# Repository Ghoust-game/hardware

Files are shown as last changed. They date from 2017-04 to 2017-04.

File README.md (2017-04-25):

# GHOUST HARDWARE

This repository is all about the **HARDWARE** used in the **GHOUST** game

You find eagle (v6) files in here
- .sch Schematics
- .brd Board layout files
- .pdf files of the Schematics 
- Bill of Materials
- Links to all Parts

Also GERBER files are provided if you want to make your own Boards

If you expect / need something that is not here, please let us know via email: team@ghou.st

Information on sourcing the parts is available on the [wiki](https://github.com/Ghoust-game/hardware/wiki).

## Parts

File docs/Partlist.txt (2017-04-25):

Part     Value            Package                     Link    

C1       0.1uF            0805                        http://mouser.com    
C2                        CPOL-RADIAL-100UF-25V       http://mouser.com   
C3       0.1uF            0805                        http://mouser.com   

D2                        SOD-123FL                   http://mouser.com   

Q2       MMBT5088         SOT23-3                     http://mouser.com   

R1       10K              R0805                       http://mouser.com    
R2       10K              R0805                       http://mouser.com   
R3       1K               R0805                       http://mouser.com   
R4       1K               R0805                       http://mouser.com   
R5       1K               R0805                       http://mouser.com   
R6       1K               R0805                       http://mouser.com   
R7       100ohm 	  R0805                       http://mouser.com   
R8       56K pullup       R0805                       http://mouser.com   

IC1      AMS1117          SOT223                      http://www.electrodragon.com/product/10pcs-ams1117-lm1117-1117-3-3v-1a-voltage-regulator/

U$1      MMA845X_BREAKOUT MMA845XBOB                  http://www.electrodragon.com/product/triple-axis-accelerometer-breakout/    
U$2      B3F-10XX_DEV     B3F-10XX                    http://www.electrodragon.com/product/mini-push-button-switch/
U$8      TRANSDUCER       BMT1205XH7.5                https://www.reichelt.at/Alarmmelder/SUMMER-EPM-121/3/index.html?ACTION=3&GROUPID=3484&ARTICLE=35927      
U$11     MICROSWITCH       			      https://www.aliexpress.com/item/6-7-2-7-1-5-3pin-slide-switch-New-products-and-ROHS/455478700.html
U$12     VIBROMOTOR       VIBRO                       https://de.aliexpress.com/item/3-Pcs-1400RPM-Speed-3V-Mobile-Phone-Micro-DC-Coin-Vibration-Motor/32695914166.html    
U$13     LIPO             LIPOCON                     https://www.aliexpress.com/item/100pcs-XH-2-5-2-54mm-2P-3P-4P-5P-6P-Female-Right-Angle-Connector-Pitch/32755811521.html
X2                        ESP-12                      http://www.electrodragon.com/product/esp-12s-wifi-module-esp8266/

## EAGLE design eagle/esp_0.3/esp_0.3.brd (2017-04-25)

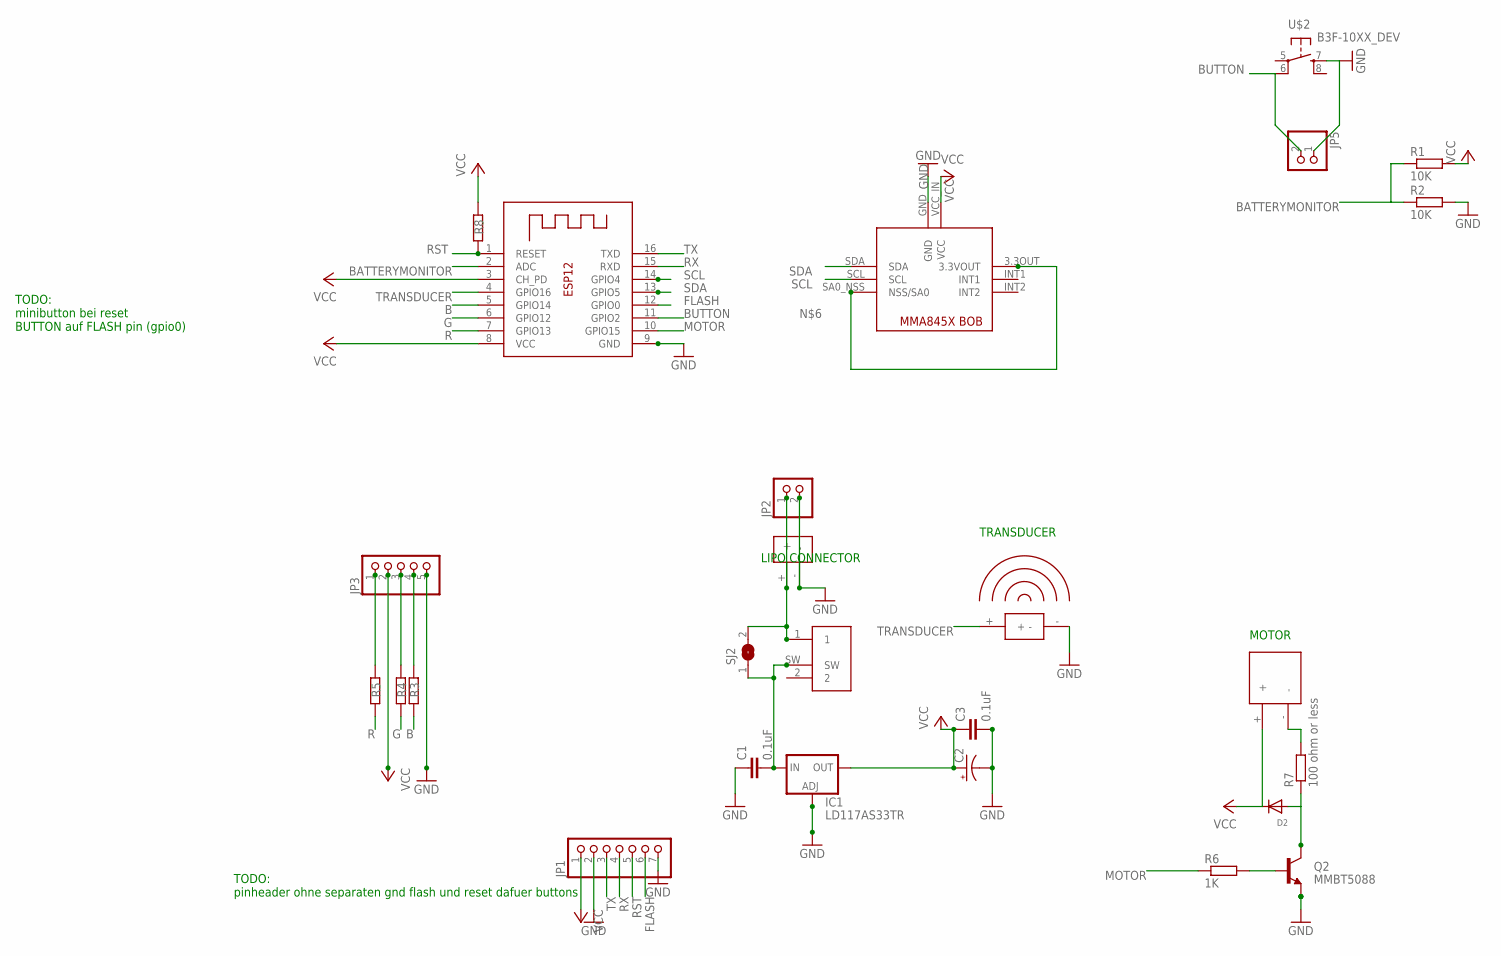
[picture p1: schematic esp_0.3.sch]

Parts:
C1, C3: 0.1uF; 0805
C2: 100UF-25V-20%(PTH); CPOL-RADIAL-100UF-25V
D2: DIODE_SOD-123FL; SOD-123FL
IC1: LD117AS33TR; SOT223
JP1: PINHD-1X7; 1X07
JP2: PINHD-1X2; 1X02
JP3: PINHD-1X5; 1X05
JP5: PINHD-1X2/90; 1X02/90
Q2: MMBT5088; SOT23-3
R1, R2: 10K; R0805
R3, R4, R5, R6: 1K; R0805
R7: 100 ohm or less; R0805
R8: 56K pullup; R0805
SJ2: SJ
U$1: MMA845X_BREAKOUT; MMA845XBOB
U$2: B3F-10XX_DEV; B3F-10XX
U$8: TRANSDUCER; BMT1205XH7.5
U$11: MICROSWITCH; MICR_SCHIEBESCHALTER_CHINA_PAC
U$12: VIBROMOTOR; VIBRO
U$13: LIPO; LIPOCON
X2: ESP-12

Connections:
B: R3.1, X2.5 (GPIO14)
BATTERYMONITOR: R1.1, R2.1, X2.2 (ADC)
BUTTON: JP5.2, U$2.6 (P1), X2.11 (GPIO2)
FLASH: JP1.6, X2.12 (GPIO0)
G: R4.1, X2.6 (GPIO12)
GND: C1.1, C2.2 (-), C3.2, IC1.1 (ADJ), JP1.2, JP1.7, JP2.2, JP3.5, JP5.1, Q2.2 (E), R2.2, U$1.GND, U$2.7 (S), U$8.-, U$13.-, X2.9 (GND)
MOTOR: R6.1, X2.10 (GPIO15)
unnamed: R7.2, U$12.-
unnamed: JP2.1, SJ2.2, U$11.1, U$13.+
unnamed: D2.A, Q2.3 (C), R7.1
unnamed: Q2.1 (B), R6.2
unnamed: C1.2, IC1.3 (IN), SJ2.1, U$11.SW
unnamed: U$1.3.3OUT (3.3VOUT), U$1.SA0_NSS (NSS/SA0)
R: R5.1, X2.7 (GPIO13)
RST: JP1.5, R8.1, X2.1 (RESET)
RX: JP1.4, X2.15 (RXD)
SCL: U$1.SCL, X2.14 (GPIO4)
SDA: U$1.SDA, X2.13 (GPIO5)
TRANSDUCER: U$8.+, X2.4 (GPIO16)
TX: JP1.3, X2.16 (TXD)
VCC: C2.1 (+), C3.1, D2.C, IC1.4 (OUT), JP1.1, JP3.2, R1.2, R8.2, U$1.VCC_IN (VCC), U$12.+, X2.3 (CH_PD), X2.8 (VCC)
XX: JP3.1, R5.2
XXX: JP3.3, R4.2
XXXX: JP3.4, R3.2

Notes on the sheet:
MOTOR
LIPO CONNECTOR
TRANSDUCER
TODO: minibutton bei reset BUTTON auf FLASH pin (gpio0)
TODO: pinheader ohne separaten gnd flash und reset dafuer buttons

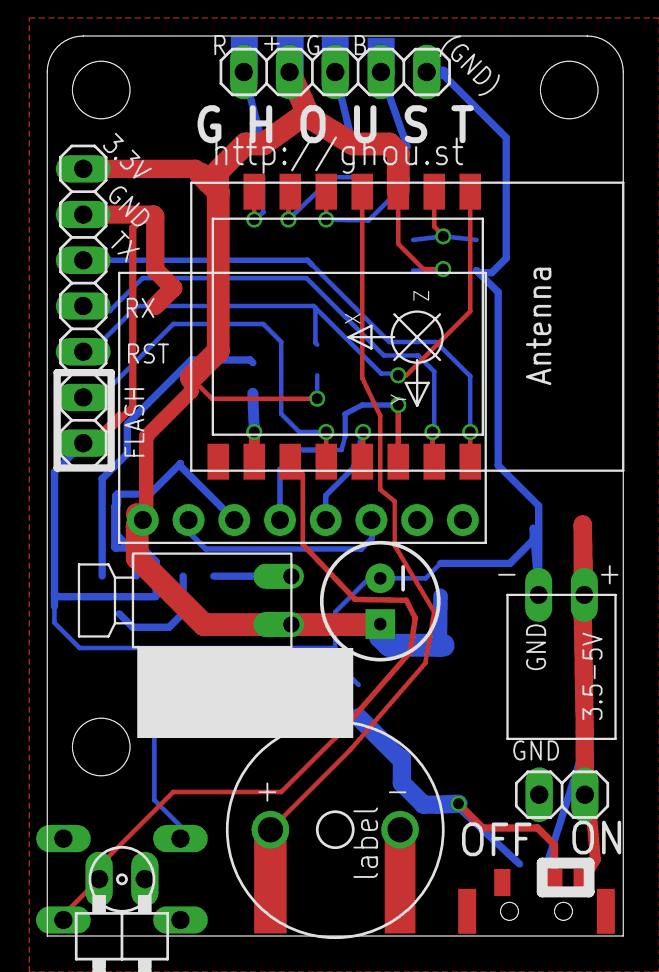
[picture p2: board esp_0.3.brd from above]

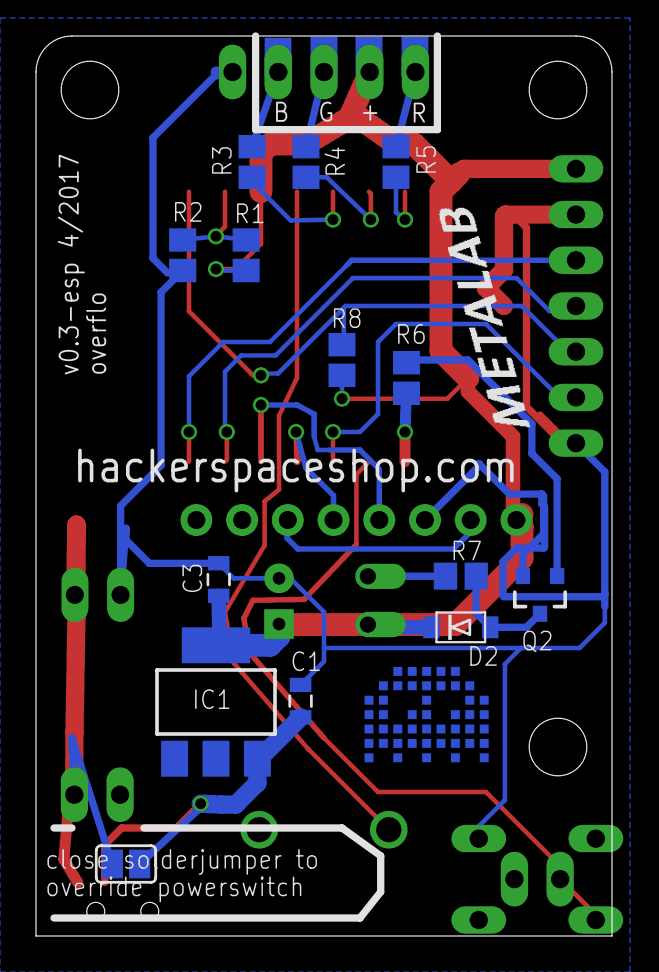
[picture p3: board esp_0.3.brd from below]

Board: 2 copper layers, 32.0 x 50.0 mm, 28 parts (16 on the bottom side), 24 nets.

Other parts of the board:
U$4: METALAB
U$6: GHOUT_LOGO; GHOUST_LOGO

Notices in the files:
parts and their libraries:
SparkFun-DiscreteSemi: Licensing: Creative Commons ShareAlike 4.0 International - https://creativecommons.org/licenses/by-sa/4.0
